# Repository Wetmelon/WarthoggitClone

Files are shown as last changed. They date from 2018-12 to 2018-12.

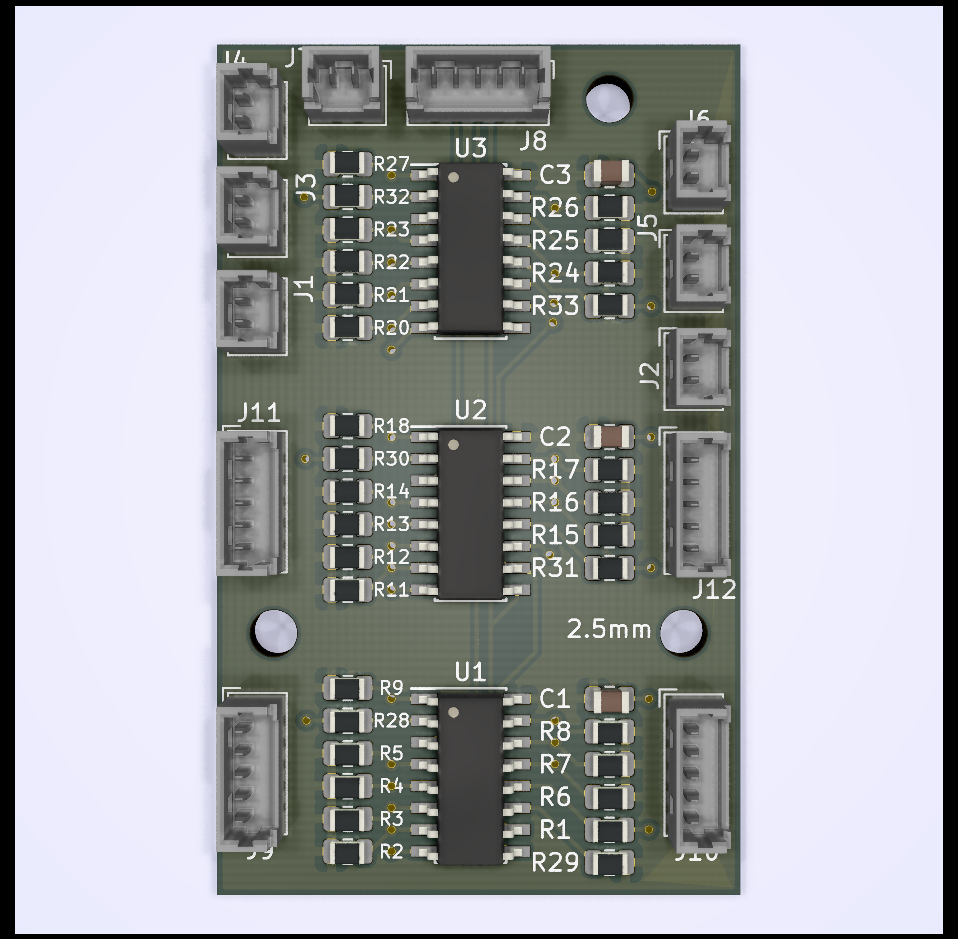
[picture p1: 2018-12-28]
Renders/Render_001.png

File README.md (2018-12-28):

# WarthoggitClone
Clone of the Warthoggit Joystick PCB

### 2-Layer
* Octopart BOM: https://octopart.com/bom-tool/HYrWh7Pe
* OSHPark PCB: https://oshpark.com/shared_projects/x2CpRCvp
* Gerblook: http://gerblook.org/pcb/NEAhkPDx7kaQgrBpLWPrQZ

### 4-Layer
* Octopart BOM: https://octopart.com/bom-tool/o3ovRzzJ
* OSHPark PCB: https://oshpark.com/shared_projects/Q2SqhzfM
* Gerblook: http://gerblook.org/pcb/AL6aAQwq3UeULmAeNpxRJG

---
## Info

Uses three cascaded 8-bit parallel-to-serial shift registers, with the final downstream output hooked to an SPI MISO line.  The whole stack is clocked by the SPI CLK and latched by SPI CS.  This variant uses automotive qualified parts to withstand the vibrations expected in a joystick.

* STM HCF4021
* Panasonic 0805 package 10k ohm resistors (can be replaced with 100k if debouncing is an issue)
* 100nF 0805 capacitors, ceramic, X7R

---

## Original Reddit Post:
https://www.reddit.com/r/hoggit/comments/46pdjy/warthoggit_pcb_series_the_circuitboard_for_your/

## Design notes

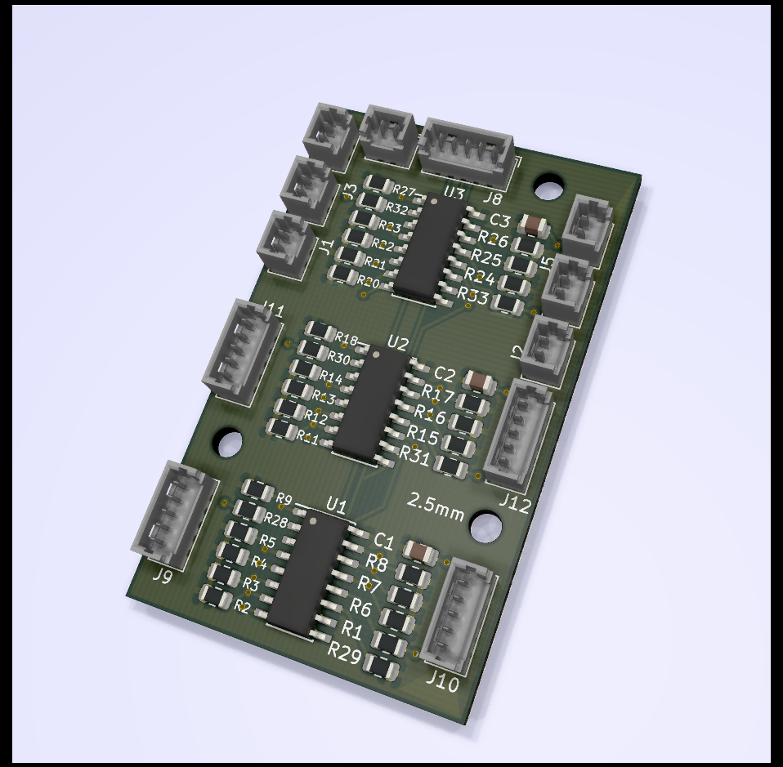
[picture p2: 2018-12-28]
Renders/Render_002.png

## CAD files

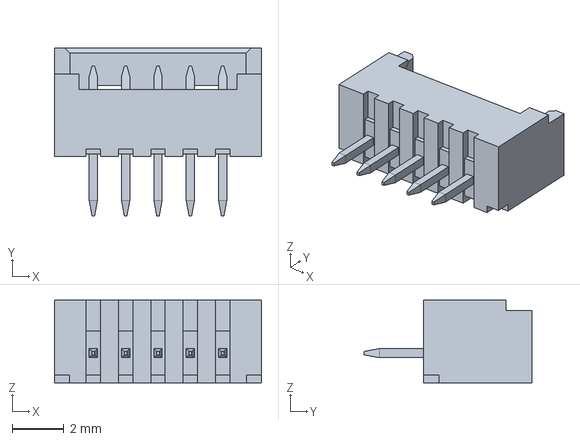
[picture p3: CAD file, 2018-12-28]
3D Models/530470510.stp
8.00 x 6.50 x 3.20 mm

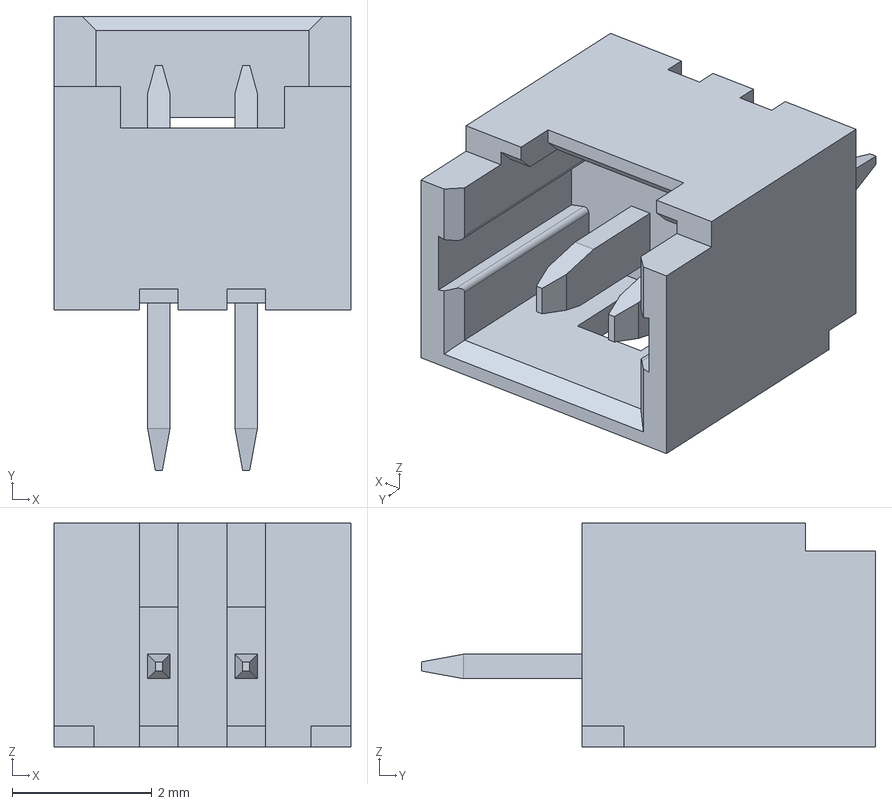
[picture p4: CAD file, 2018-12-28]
3D Models/530470210.stp
4.25 x 6.50 x 3.20 mm

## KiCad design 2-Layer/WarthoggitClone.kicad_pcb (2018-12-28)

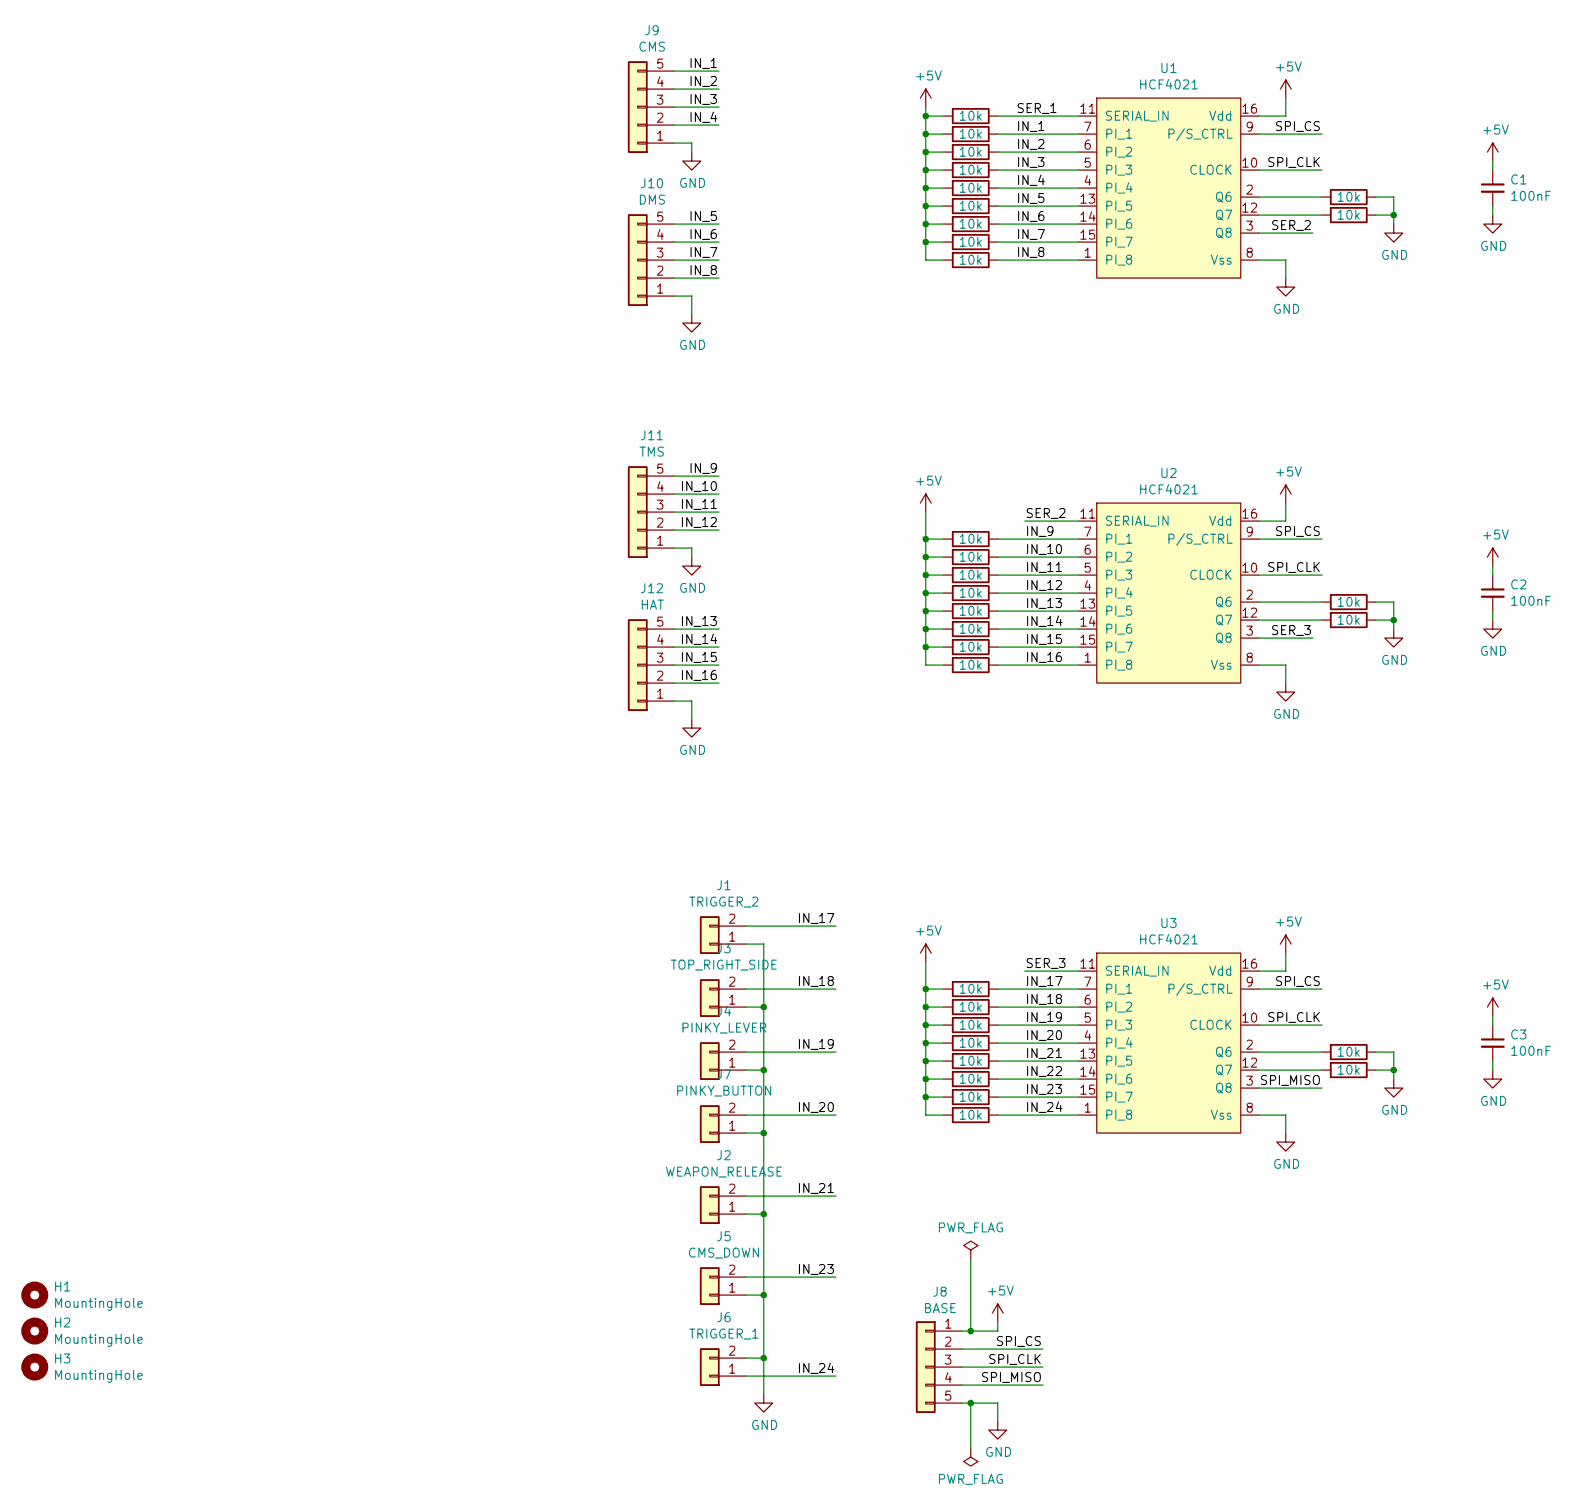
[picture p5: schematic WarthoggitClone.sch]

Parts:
C1, C2, C3: 100nF; C_0805_2012Metric
H1, H2, H3: MountingHole; MountingHole_2.7mm_M2.5
J1: TRIGGER_2; Molex_PicoBlade_53047-0210_1x02_P1.25mm_Vertical
J2: WEAPON_RELEASE; Molex_PicoBlade_53047-0210_1x02_P1.25mm_Vertical
J3: TOP_RIGHT_SIDE; Molex_PicoBlade_53047-0210_1x02_P1.25mm_Vertical
J4: PINKY_LEVER; Molex_PicoBlade_53047-0210_1x02_P1.25mm_Vertical
J5: CMS_DOWN; Molex_PicoBlade_53047-0210_1x02_P1.25mm_Vertical
J6: TRIGGER_1; Molex_PicoBlade_53047-0210_1x02_P1.25mm_Vertical
J7: PINKY_BUTTON; Molex_PicoBlade_53047-0210_1x02_P1.25mm_Vertical
J8: BASE; Molex_PicoBlade_53047-0510_1x05_P1.25mm_Vertical
J9: CMS; Molex_PicoBlade_53047-0510_1x05_P1.25mm_Vertical
J10: DMS; Molex_PicoBlade_53047-0510_1x05_P1.25mm_Vertical
J11: TMS; Molex_PicoBlade_53047-0510_1x05_P1.25mm_Vertical
J12: HAT; Molex_PicoBlade_53047-0510_1x05_P1.25mm_Vertical
R1, R2, R3, R4, R5, R6, R7, R8, R9, R11, R12, R13, R14, R15, R16, R17, R18, R20, R21, R22, R23, R24, R25, R26, R27, R28, R29, R30, R31, R32, R33: 10k; R_0805_2012Metric
U1, U2, U3: HCF4021; SOIC-16_3.9x9.9mm_P1.27mm

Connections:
+5V: C1.1, C2.1, C3.1, J8.1, R1.2, R2.2, R3.2, R4.2, R5.2, R6.2, R7.2, R8.2, R9.2, R11.2, R12.2, R13.2, R14.2, R15.2, R16.2, R17.2, R18.2, R20.2, R21.2, R22.2, R23.2, R24.2, R25.2, R26.2, R27.2, U1.16 (Vdd), U2.16 (Vdd), U3.16 (Vdd)
/IN_1: J9.5, R2.1, U1.7 (PI_1)
/IN_2: J9.4, R3.1, U1.6 (PI_2)
/IN_3: J9.3, R4.1, U1.5 (PI_3)
/IN_4: J9.2, R5.1, U1.4 (PI_4)
/IN_5: J10.5, R6.1, U1.13 (PI_5)
/IN_6: J10.4, R7.1, U1.14 (PI_6)
/IN_7: J10.3, R8.1, U1.15 (PI_7)
/IN_8: J10.2, R9.1, U1.1 (PI_8)
/IN_9: J11.5, R11.1, U2.7 (PI_1)
/IN_10: J11.4, R12.1, U2.6 (PI_2)
/IN_11: J11.3, R13.1, U2.5 (PI_3)
/IN_12: J11.2, R14.1, U2.4 (PI_4)
/IN_13: J12.5, R15.1, U2.13 (PI_5)
/IN_14: J12.4, R16.1, U2.14 (PI_6)
/IN_15: J12.3, R17.1, U2.15 (PI_7)
/IN_16: J12.2, R18.1, U2.1 (PI_8)
/IN_17: J1.2, R20.1, U3.7 (PI_1)
/IN_18: J3.2, R21.1, U3.6 (PI_2)
/IN_19: J4.2, R22.1, U3.5 (PI_3)
/IN_20: J7.2, R23.1, U3.4 (PI_4)
/IN_21: J2.2, R24.1, U3.13 (PI_5)
/IN_22: R25.1, U3.14 (PI_6)
/IN_23: J5.2, R26.1, U3.15 (PI_7)
/IN_24: J6.1, R27.1, U3.1 (PI_8)
/SER_1: R1.1, U1.11 (SERIAL_IN)
/SER_2: U1.3 (Q8), U2.11 (SERIAL_IN)
/SER_3: U2.3 (Q8), U3.11 (SERIAL_IN)
/SPI_CLK: J8.3, U1.10 (CLOCK), U2.10 (CLOCK), U3.10 (CLOCK)
/SPI_CS: J8.2, U1.9 (P/S_CTRL), U2.9 (P/S_CTRL), U3.9 (P/S_CTRL)
/SPI_MISO: J8.4, U3.3 (Q8)
GND: C1.2, C2.2, C3.2, J1.1, J2.1, J3.1, J4.1, J5.1, J6.2, J7.1, J8.5, J9.1, J10.1, J11.1, J12.1, R28.1, R29.1, R30.1, R31.1, R32.1, R33.1, U1.8 (Vss), U2.8 (Vss), U3.8 (Vss)
unnamed: R28.2, U1.2 (Q6)
unnamed: R29.2, U1.12 (Q7)
unnamed: R30.2, U2.2 (Q6)
unnamed: R31.2, U2.12 (Q7)
unnamed: R32.2, U3.2 (Q6)
unnamed: R33.2, U3.12 (Q7)

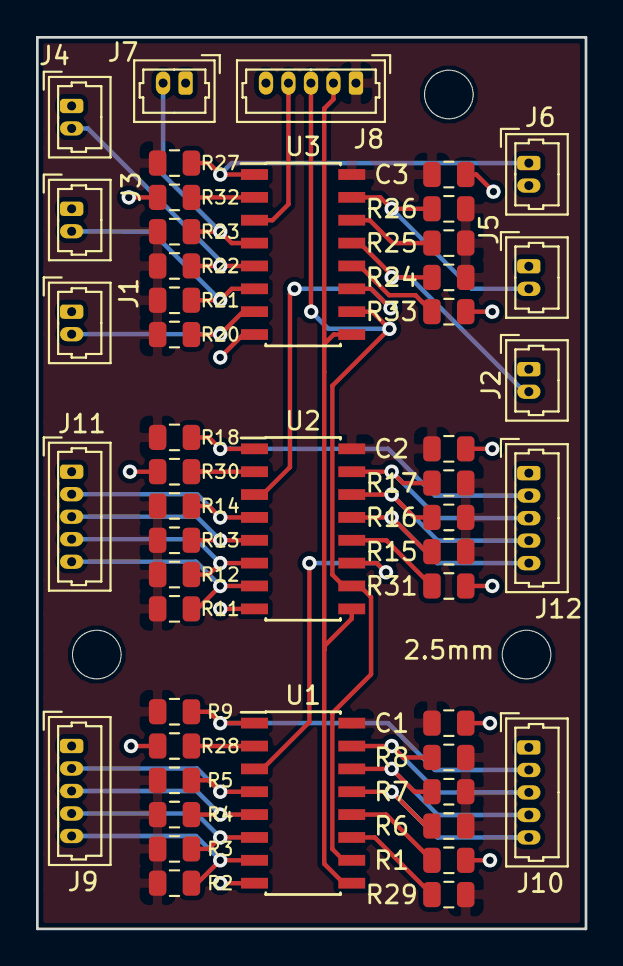
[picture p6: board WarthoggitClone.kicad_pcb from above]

Board: 2 copper layers, 30.5 x 49.5 mm, 52 parts (0 on the bottom side), 38 nets.

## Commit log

2018-12-28 Add Gerbers
    [WarthoggitClone-B.Cu.gbl, WarthoggitClone-B.Mask.gbs, WarthoggitClone-B.Paste.gbp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]
2018-12-28 Fix DRC
    [WarthoggitClone.kicad_pcb]
2018-12-28 Add 4Layer files
    [WarthoggitClone_4Layer.kicad_pcb, WarthoggitClone_4Layer.sch]
2018-12-28 Split files into folders, fix missing 3D model in picoblade footprints
    [WarthoggitClone.kicad_pcb, WarthoggitClone.sch, WarthoggitClone_4Layer.kicad_pcb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]
2018-12-28 Generate 4 layer gerbers
    [WarthoggitClone-B.Cu.gbl, WarthoggitClone-B.Mask.gbs, WarthoggitClone-B.Paste.gbp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]
2018-12-28 Add zip file for 4 layer gerbers
